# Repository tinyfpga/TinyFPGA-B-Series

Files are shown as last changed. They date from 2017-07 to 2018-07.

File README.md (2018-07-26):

[](https://travis-ci.org/tinyfpga/TinyFPGA-B-Series)

# TinyFPGA B2 Board
The TinyFPGA B2 board is a tiny FPGA board with a low cost per logic element and convenient USB bitstream programming capability.  It measures just 18mm x 36mm and is a perfect fit for breadboards.  

# TinyFPGA BX Repo has Moved
If you are looking for the TinyFPGA BX design files and examples, it is in a seperate repository: [TinyFPGA BX GitHub Repo](https://github.com/tinyfpga/TinyFPGA-BX).

## Features
The heart of the B-series boards is either a ICE40LP4K or ICE40LP8K FPGA from Lattice.  For full details on the ICE40 series of FPGAs you can read the [ICE40 Family Handbook](http://www.latticesemi.com/~/media/LatticeSemi/Documents/Handbooks/iCE40FamilyHandbook.pdf).

### FPGA Feature Summary
| | TinyFPGA B1 | TinyFPGA B2 |
|---|:---:|:---:|
| FPGA Chip |  ICE40LP4K  |  ICE40LP8K  |
| Logic Cells | 3,520 | 7,680 |
| Block RAM Bits | 80 KBit | 128 KBit  |
| Phase Lock Loops | 1 | 1 |
| User IO Pins | 23 | 23 |

### Common Features
+ Small form-factor that is breadboard friendly; plenty of space on either side for connecting jumpers or components.
+ Built-in USB interface for programming new FPGA bitstreams and user data to flash.
+ [4MBit of SPI Flash](http://datasheet.octopart.com/AT25SF041-SSHD-B-Adesto-Technologies-datasheet-62342976.pdf)
  + Bootloader bitstream takes up about 1MBit, user design bitstream will take another 1MBit, the rest is free to use for other purposes.
+ 3.3v and 1.2v Regulators
  + [3.3v LDO regulator](http://datasheet.octopart.com/MIC5504-3.3YM5-TR-Micrel-datasheet-61114938.pdf) can supply up to 300ma of current.  This leaves some headroom for user peripherals.
  + [1.2v LDO regulator](http://datasheet.octopart.com/MIC5365-1.2YC5-TR-Microchip-datasheet-8324343.pdf) can supply up to 150ma of current.  More headroom for user peripherals.
+ [Ultra Low-Power 16MHz MEMs Oscillator](http://www.mouser.com/ds/2/268/20005625A-1022977.pdf)
  + Consumes 1.3ma power when active.  
  + 50ppm stability

## Building your own TinyFPGA B1 or B2 Boards
It is possible to build the TinyFPGA B-Series boards by hand in a home lab.  However, it uses tiny 0402 surface mount capacitors and resistors and the ICE40 FPGAs used are in a 81 ball BGA package with 0.4mm pitch between the balls.  It is a challenging undertaking and will most likely result in some bad assembled boards along with the good.  I have used the following with success to hand assemble the prototype boards:
+ Parts for the TinyFPGA [B1](https://octopart.com/bom-tool/v110mo4B) or [B2](https://octopart.com/bom-tool/D9LH87Em)
+ [Lead-Free Solder Paste](https://www.amazon.com/gp/product/B00HKK6XHC)
+ [Stainless Steel Solder Paste Squeegee](http://dirtypcbs.com/store/details/14/solder-paste-squeegee)
+ [TinyFPGA B-Series Solder Paste Stencil](https://www.oshstencils.com)
  + You'll need to generate the gerber files and upload the solder paste layer.  You will want the stainless steel stencil, I do not believe the polymide will work with the fine pitch BGA package.
+ [TinyFPGA B-Series PCBs](https://oshpark.com/shared_projects/jGc1k4QL)
  + These boards require tighter tolerances than OSH Park advertises.  However, I have gotten lucky with some boards from OSH Park for this project and they have worked well.
+ [Precision Tweezers](https://www.amazon.com/Precision-Anti-static-Marrywindix-Electronics-Jewelry-making/dp/B00DVIEJ14) for placing parts on the board
+ Some sort of magnifying tool for placing parts ([magnifying glasses](https://www.amazon.com/dp/B01H8808H6), [magnifying lamp](https://www.amazon.com/Brightech-LightView-SuperBright-Magnifier-Adjustable/dp/B00UW2IRJ2), microscope)
+ [Reflow Oven](http://www.whizoo.com/)
  + I was using an electric griddle to reflow the A-series boards and it worked well enough.  However I didn't bother trying that with the micro BGA package on the B-series boards and I got a reflow oven kit.  This particular kit is excellent.
+ [Lattice FPGA Programmer](https://www.ebay.com/sch/i.html?_productid=533163279) or [Arduino board](https://www.arduino.cc/)
  + You will need this to load the bootloader onto the SPI Flash.  Once the bootloader is installed you can use the Python-based programmer application to program the board over USB.
  + Look in the [`programmer_arduino`](programmer_arduino) folder to load the bootloader onto the SPI Flash using an Arduino.

## Buy TinyFPGA B1 or B2 Boards
If you don't want to go through the hassle of ordering parts, tools, and supplies and assembling the boards yourself you can order professionally assembled and tested boards from [Tindie](https://www.tindie.com/stores/tinyfpga/) or the [TinyFPGA Store](http://store.tinyfpga.com).  These boards are not hobbyist-made, they are fabricated and assembled in a professional PCB fab that manufactures and assembles many other consumer, industrial and military electronics.  They go through an automated testing and programming process to ensure the board is healthy and ready to program over USB.

## Project Directory Structure
### board
This contains a [KiCad](http://kicad-pcb.org/) project with the schematic and layout of the B-series boards.  The board is designed with 4/4mil track size/spacing and 0.2mm hole size.  BOM lists for B1 and B2 boards are available here as well.

### bootloader
FPGA boards with USB bitstream programming capability typically use an expensive USB interface chip to provide this functionality.  The TinyFPGA B-series implement the USB bitstream programming capability within the FPGA itself.  This directory contains the verilog code that implements this bootloader.  The code is organized as an [iCEcube2](http://www.latticesemi.com/iCEcube2) project.  The bootloader itself works in the same way an Arduino bootloader works.  It is the first design to boot on the FPGA, if it is connected to a USB host it waits for a new bitstream to be programmed to the SPI flash, then reboots the FPGA to load the user design from flash.  If the board is not connected to a USB host or if there is no programmer application running on the host then the bootloader will quickly timeout and load the user design.  The bootloader does not consume any FPGA resources while the user design is loaded.

### programmer
The bootloader uses a simple protocol over a generic USB serial interface.  This directory contains a Python module for interfacing with the bootloader as well as a friendly Python GUI application for selecting and programming bitstreams.

### template
This is a template iCEcube2 project for developing your own designs to program onto the board.  It takes care of pin and clock constraints.  Just edit the TinyFPGA_B.v file to add your designs module(s).

## Project Log
For more information on the development and production of the B-Series please read and follow the [TinyFPGA B-Series Project Page](https://hackaday.io/project/26848-tinyfpga-b-series) at hackaday.io.

## License
The TinyFPGA B-Series project is an open source project licensed under GPLv3.  Please see the included LICENSE file for details.  If you do wish to distribute boards derived from this open source hardware project then you must also release the source files for the boards under GPLv3.  You are free to do this, but please improve upon the original design and provide a tangible benefit for users of the board.

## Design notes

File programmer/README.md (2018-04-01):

# Programmer

## Directory Structure

The programmer Python code is organized in a Python package.  The actual code for the programmer is located in the `tinyfpgab` directory in the `__init__.py` and `__main__.py` files.  The `setup.py` script is specific to the Python packaging system and should be be executed directly.  If you want to learn more about Python packaging take a look at the [Python packaging documentation](http://python-packaging.readthedocs.io/en/latest/minimal.html).  If you just want to run the programmer on the command-line, the best way is to install it using pip: `pip install tinyfpgab`.  The programmer script will then be added to your `PATH` variable as `tinyfpgab`.

## GUI

The GUI has been moved to the [TinyFPGA Programmer Application repo][gui-repo].
However, the `tinyfpgab` module can be used on its own with a command-line
interface:

[gui-repo]: https://github.com/tinyfpga/TinyFPGA-Programmer-Application

## CLI Installation

Install the commandline tool via Python's pip tool:
```
> pip install tinyfpgab
```

## CLI Usage
```
> tinyfpgab --help
usage: tinyfpgab [-h] [-l] [-p PROGRAM] [-b] [-c COM] [-d DEVICE] [-a ADDR]

optional arguments:
  -h, --help            show this help message and exit
  -l, --list            list connected and active TinyFPGA B-series boards
  -p PROGRAM, --program PROGRAM
                        program TinyFPGA board with the given bitstream
  -b, --boot            command the TinyFPGA B-series board to exit the
                        bootloader and load the user configuration
  -c COM, --com COM     serial port name
  -d DEVICE, --device DEVICE
                        device id (vendor:product); default is TinyFPGA-B
                        (1209:2100)
  -a ADDR, --addr ADDR  force the address to write the bitstream to
```

You can list valid ports with the `--list` option:

```
> tinyfpgab --list

    TinyFPGA B-series Programmer CLI
    --------------------------------
    Boards with active bootloaders:
        COM24

```

You can use the `--com` option to specify a specific port.  If you don't specify a port, it will use the first one in the list:

```
> tinyfpgab --program ..\icestorm_template\TinyFPGA_B.bin

    TinyFPGA B-series Programmer CLI
    --------------------------------
    Programming COM24 with ..\icestorm_template\TinyFPGA_B.bin
    Waking up SPI flash
    135100 bytes to program
    Erasing designated flash pages
    Writing bitstream
    Verifying bitstream
    Success!

```

## Testing

The tests can be run with [tox](https://tox.readthedocs.io/): just run the `tox` command.  If you don't have `tox` installed, read the tox documentation and install it first.

The code coverage will be generated as HTML pages in the `htmlcov` directory.

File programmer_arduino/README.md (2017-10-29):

# Programming with an Arduino

Programming the TinyFPGA using an Arduino (or compatible board) is useful in
the following cases:

 * You have overridden the TinyFPGA bootloader, so you cannot program the board
   any more and need a way to upload the bootloader again.

 * You have a project that needs a lot data to be stored in the Flash memory,
   and leaving the bootloader there takes too much place. In that case, simply
   upload your bitstream at the address `0` and you are free to use the
   remaining space.

## Hardware

:warning: **The TinyFPGA board is expecting 3.3V, but the Arduino board is
typically outputting 5V! We explain below how to go from 5V to 3.3V.**
:warning:

The following connections will be made:

| Arduino pin | TinyFPGA pin | Comment |
| :---: | :---: | :---: |
| 3.3V | 3.3V | |
| GND | G | |
| 10 | 17 | Through 5V-to-3.3V converter |
| 11 | 14 | Through 5V-to-3.3V converter |
| 12 | 15 | Through 5V-to-3.3V converter |
| 13 | 16 | Through 5V-to-3.3V converter |

To convert from 5V to 3.3V, a solution is to use a [voltage
divider](https://en.wikipedia.org/wiki/Voltage_divider) made of a few
resistors. By using `R1=470Ω` and `R2=1kΩ`, we should have an output close to
3.4V, which should be good:

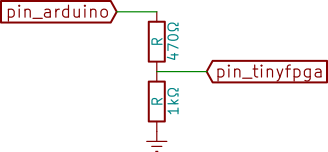
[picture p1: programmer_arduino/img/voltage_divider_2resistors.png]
Voltage divider with 2 resistors


If you don't have those specific resistor values, just take the same value
three times, the output should be close to 3.3V:

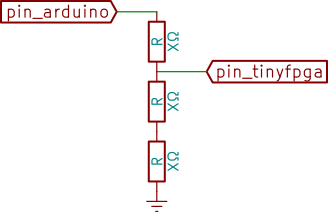
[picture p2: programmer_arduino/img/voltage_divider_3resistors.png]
Voltage divider with 3 resistors


The following shows all connections between the two boards:

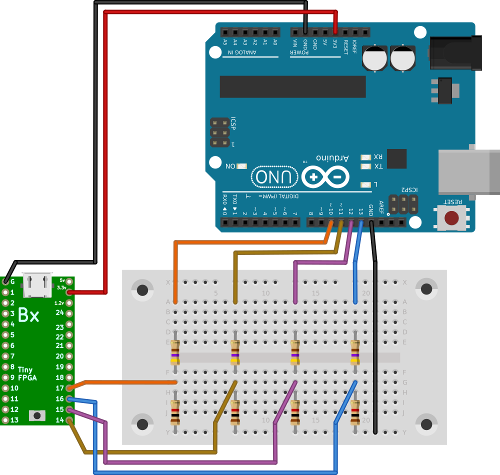
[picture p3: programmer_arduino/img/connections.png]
Overview


:warning: The TinyFPGA USB port should not be plugged at all at that point,
you can plug the Arduino board instead. :warning:

## Uploading the Arduino bootloader with PlatformIO

[PlatformIO](http://platformio.org/) is an open source ecosystem that make
using Arduino and other boards a breathe.

Once installed on your system, start by initialising the project from this
directory  (using the Arduino UNO board as an example):

    $ platformio init --board uno

Then, build the project and upload it to your Arduino:

    $ platformio run --target upload

That's all!

## Using the Arduino to program the TinyFPGA

We are going to use [the programmer CLI](../programmer).

First, find the vendor and product ID of your Arduino board. Doing so depends
on your operating system. For example on GNU/Linux:

    $ lsusb
    --<snip>--
    Bus 001 Device 002: ID 2341:0001 Arduino SA Uno (CDC ACM)
    --<snip>--

Now, use that vendor-product ID to program the Flash via the Arduino:

    $ ../programmer/tinyfpgab.py -d 2341:0001 -a 0 -p /snip/bootloader.bin

Notice the following in the command above:

 * The `-d` parameter specifies the device ID (vendor:product)
 * The `-a` parameter gives the address at which to program the bitstream: here
   we are writing at address 0, which is the correct address to put the
   TinyFPGA bootloader at.

Depending on the bitstream run by the FPGA, you may need to do the following:

 * Disconnect the Arduino from your computer, plug it back, and try again
 * Do the same, but this time press the reset button once before programming
 * Do the same, but this time hold the reset button before programming and
   *during the whole programming operation*: it is likely to last a minute or
   two, so be patient or use some non-metallic tool to hold the reset button
   down (a wooden clothes peg seems to do the job)

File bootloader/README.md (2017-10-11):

# USB Bootloader
The USB Bootloader implements a USB virtual serial port to SPI flash bridge.  From the host computer's perspective, it looks like a serial port.  This method was chosen because programming with serial ports is generally easier to understand than other USB-specific protocols.  Commands boot into the user configuration or access the SPI flash are all transfered over this interface.  

## Protocol
The protocol on top of the USB virtual serial port takes the form of requests and responses.  Only the host computer is able to initiate requests.  The bootloader on the FPGA can only respond to requests.

### Boot Command
```
Length: 1 byte

+=====================+
|    Request Data     |
+=====+========+======+
| Byte| Field  |Value |
+=====+========+======+
|  0  | Opcode | 0x00 |
+-----+--------+------+
```

The `Boot` command forces the TinyFPGA B-series board to exit the bootloader and configure the FPGA with the user design from SPI flash.  Once the user design is loaded onto the FPGA, the bootloader is no longer present and the user design has full control over the FPGA, including the USB interface.   

### Access SPI Command
```
Length: Variable

+================================+
|          Request Data          |
+=====+===================+======+
| Byte|       Field       | Value|
+=====+===================+======+
|  0  |       Opcode      | 0x01 |
+-----+-------------------+------+
|  1  |  Write Length Lo  | 0xWW |
+-----+-------------------+------+
|  2  |  Write Length Hi  | 0xWW |
+-----+-------------------+------+
|  3  |   Read Length Lo  | 0xRR |
+-----+-------------------+------+
|  4  |   Read Length Hi  | 0xRR |
+-----+-------------------+------+
|  5  | Write Data Byte 0 | 0xDD |
+-----+-------------------+------+
+-----+-------------------+------+
| n+5 | Write Data Byte n | 0xDD |
+-----+-------------------+------+

+================================+
|         Response Data          |
+=====+===================+======+
| Byte|       Field       | Value|
+=====+===================+======+
|  0  |  Read Data Byte 0 | 0xDD |
+-----+-------------------+------+
+-----+-------------------+------+
|  n  |  Read Data Byte n | 0xDD |
+-----+-------------------+------+
```

**NOTE: Even though the read and write fields are two bytes long, the current bootloader only supports read and write lengths of up to 16 bytes.  It will crash if larger lengths are used.**

The `Access SPI` command executes a transfer with the SPI flash.  SPI flash commands can have two phases:
1. Write phase.  Command opcode, address, and potentially data are shifted out the SPI master to the SPI flash.
2. Read phase.  Data is shifted from the SPI flash to the SPI master.

The `Write Length` and `Read Length` in the `Access SPI` command refer to these two phases.  In order to fully understand how to interact with the SPI flash you need to read the [datasheet for the SPI flash chip](http://datasheet.octopart.com/AT25SF041-SSHD-B-Adesto-Technologies-datasheet-62342976.pdf).  The datasheet contains a table that lists the commands the SPI flash chip supports.  

Here's a summary of the commands used to properly erase, program, and verify bitstreams on the SPI flash:

| Command | Opcode | Address Bytes | Dummy Bytes | Data Bytes | Datasheet Section |
|---|:---:|:---:|:---:|:---:|:---:|
| Resume | 0xAB | 0 | 0 | 0 | 11.4 |
| Read Man. and Dev. ID | 0x9F | 0 | 0 | 0 | 11.1 |
| Read Status Reg 1 | 0x05 | 0 | 0 | 1 | 10.1 |
| Block Erase 4 KBytes  | 0x20 | 3 | 0 | 0 | 7.2 |
| Block Erase 32 KBytes | 0x52 | 3 | 0 | 0 | 7.2 |
| Block Erase 64 KBytes | 0xD8 | 3 | 0 | 0 | 7.2 |
| Write Enable | 0x06 | 0 | 0 | 0 | 8.1 |
| Byte/Page Program | 0x02 | 3 | 0 | 1+ | 7.1 |
| Read Array | 0x0B | 3 | 1 | 1+ | 6.1 | 

## SPI Flash Programming Flow

The SPI flash needs to be accessed in a specific order to successfully program the bitstream.  The following pseudocode illustrates how the `tinyfpgab.py` programmer accesses the SPI flash:

```
// SPI flash will be in deep sleep, we need to wake it up
Issue Resume command     

// these two commands work around a bootloader bug
Read Status Register        
Read 16 bytes from addr 0  

// erase user flash area
For each 4k block from (0x30000) to (0x30000 + length(bitstream)):
    Issue Block Erase 4 KBytes at current block address
    Poll Read Status Reg 1 until bit 0 is cleared

// program new user bitstream into user flash area
For each 16 bytes from (0x30000) to (0x30000 + length(bitstream)):
    Issue write enable command
    Write 16 bytes of of the bitstream and increment write offset by 16 bytes
    
// verify bitstream data is correct
For each 16 bytes from (0x30000) to (0x30000 + length(bitstream)):
    Read 16 bytes of of the bitstream, compare to bitstream file, and increment read offset by 16 bytes

Issue Boot command to the bootloader
```

For exact details, see the [tinyfpgab.py](https://github.com/tinyfpga/TinyFPGA-B-Series/blob/master/programmer/tinyfpgab.py) programming script in this repo.

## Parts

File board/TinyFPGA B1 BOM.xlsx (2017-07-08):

Qty | Manufacturer | MPN | Schematic Reference | Description | Package | Polarity
1 | FCI | 10118192-0001LF | J3 | USB Micro Connector |  | pin locations only allow one correct orientation
1 | Microchip | MIC5365-1.2YC5-TR | U4 | 1.2v LDO |  | pin locations only allow one correct orientation
1 | Microchip | MIC5504-3.3YM5-TR | U2 | 3.3v LDO |  | pin locations only allow one correct orientation
4 | Murata | GRM155R61A105KE15D | C1, C2, C3, C4 | 1uF Ceramic Capacitor, 10V, X7R, 10% | 0402 | no polarity
1 | Lattice Semiconductor | ICE40LP4K-CM81 | U1 | FPGA | CM81 | circle on package at pin 1,
1 | Microchip | DSC6001CI2A-016.0000T or DSC6001CI2A-016.0000 | U3 | 16MHz Clock | CDFN3225-4LD-PL-1 | circle on package at pin 1
1 | Adesto Technologies | AT25SF041-SSHD-B | U5 | 4MBit SPI Flash | SOIC-8 3.9x4.9mm Pitch1.27mm | slight divot on package at pin 1
1 | C&K Components | PTS810 SJM 250 SMTR LFS | SW1 | Reset/Program Button |  | button is slightly wider in one dimension
3 | Vishay | CRCW040210K0FKED | R5, R6, R7 | 10k resistor, 1% tolerance, 1/16 watt | 0402 | no polarity
1 | KOA | RK73H1ETTP1000F | R4 | 100ohm resistor, 1% tolerance, 1/10 watt | 0402 | no polarity
2 | Panasonic | ERJ-2RKF68R0X | R2, R3 | 68ohm resistor, 1% tolerance, 1/10 watt | 0402 | no polarity
1 | Bourns | CR0402-FX-1501GLF | R1 | 1.5k resistor, 1% tolerance, 1/16 watt | 0402 | no polarity
4 | Wurth Electronics | 885012205050 | C12, C13, C14, C15 | 10nF Ceramic Capacitor, 25V, X7R, 10% | 0402 | no polarity
7 | Wurth Electronics | 885012105018 | C5, C7, C8, C9, C10, C11, C16 | 100nF Ceramic Capacitor, 25V, X5R, 10% | 0402 | no polarity
2 | TDK | C1608X5R0J106M080AB | C6, C17 | 10uF Ceramic Capacitor, 6.3V, X5R, 20% | 0603 | no polarity
1 | Murata | BLM18PG300SN1D | L1 | Ferrite Bead, 30ohm@100MHz impedance, 50mOhm DC resistance | 0603 | no polarity
 |  | Green items may be substituted with parts that have identical or better specifications
 |  | Red items may not be substituted with different part numbers

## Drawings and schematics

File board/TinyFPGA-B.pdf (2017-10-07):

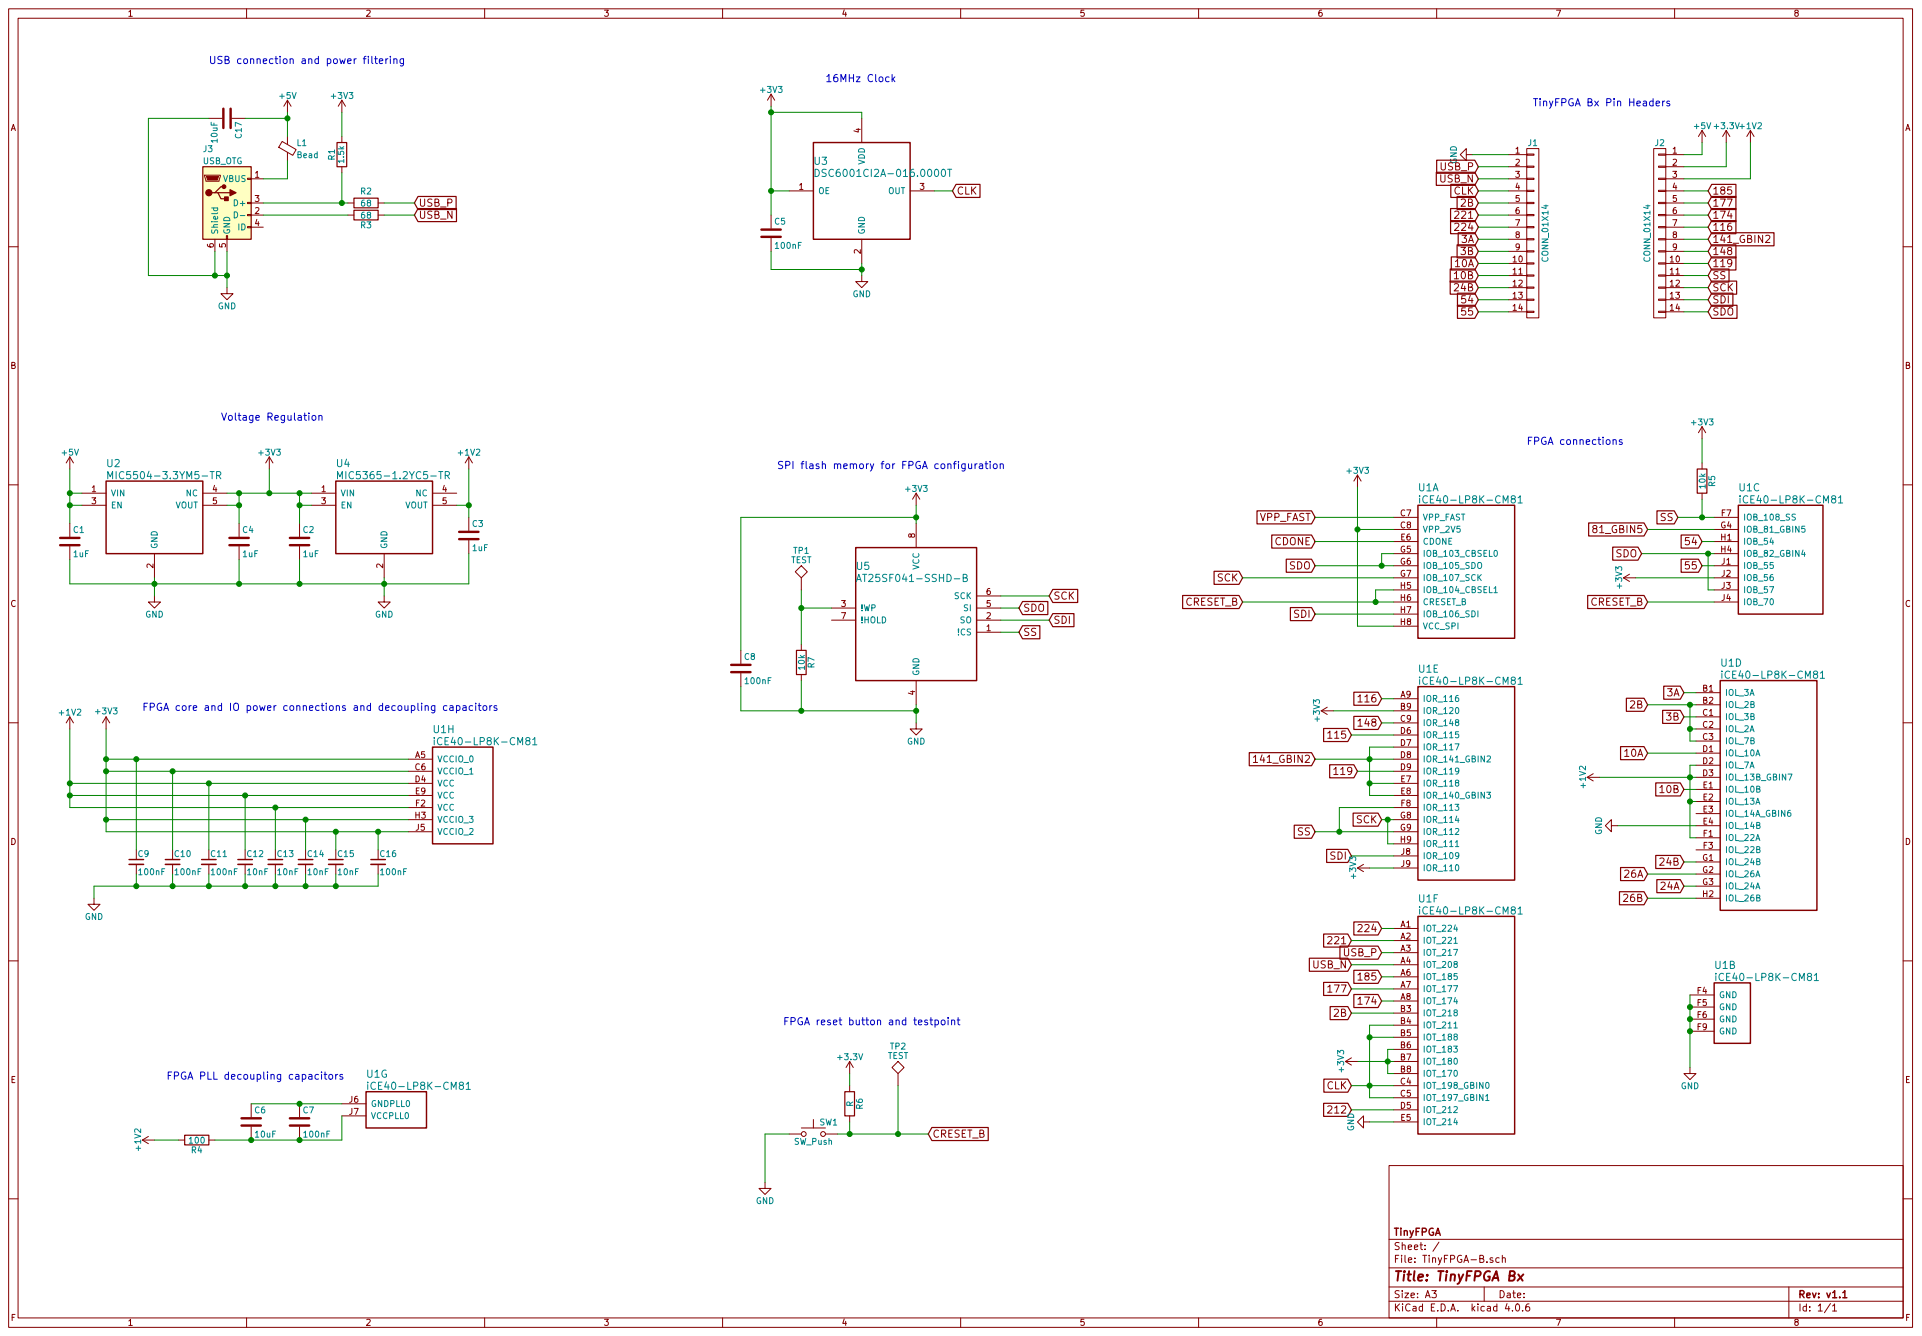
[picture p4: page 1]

USB connection and power filtering

TinyFPGA Bx Pin Headers

SPI flash memory for FPGA configuration

TP2 TEST FPGA core and IO power connections and decoupling capacitors

FPGA reset button and testpoint

FPGA PLL decoupling capacitors

File: TinyFPGA-B.sch Sheet: / TinyFPGA

Id: 1/1 Title: TinyFPGA Bx

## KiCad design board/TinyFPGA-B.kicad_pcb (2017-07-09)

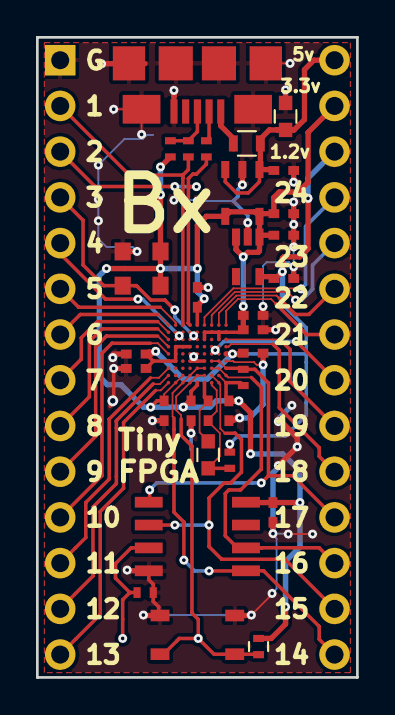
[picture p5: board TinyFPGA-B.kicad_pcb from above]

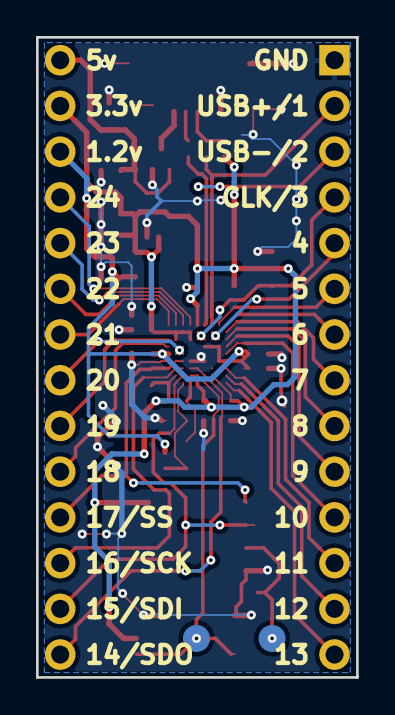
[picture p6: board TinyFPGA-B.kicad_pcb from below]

Board: 2 copper layers, 17.8 x 35.6 mm, 36 parts (2 on the bottom side), 35 nets.

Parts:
C1, C2, C3, C4: 1uF; C_0402_NoSilk
C5, C7, C8, C9, C10, C11, C16: 100nF; C_0402_NoSilk
C6, C17: 10uF; C_0603
C12, C13, C14, C15: 10nF; C_0402_NoSilk
J1, J2: CONN_01X14; Pin_Header_Straight_1x14_Pitch2.54mm
J3: USB_OTG; USB_Micro-B_Molex_47346-0001
L1: Bead; L_0603
R1: 1.5k; R_0402_NoSilk
R2, R3: 68; R_0402_NoSilk
R4: 100; R_0402_NoSilk
R5, R7: 10k; R_0402_NoSilk
R6: 100; R_0402
SW1: SW_Push; PTS_810_SMT_Switch
TP1, TP2: TEST; Measurement_Point_Round-SMD-Pad_Small
U1: iCE40-LP8K-CM81; CM81
U2: MIC5504-3.3YM5-TR; SC-70-C5
U3: DSC6001CI2A-016.0000T; CDFN3225-4LD-PL-1
U4: MIC5365-1.2YC5-TR; SC-70-C5
U5: AT25SF041-SSHD-B; SOIC-8_3.9x4.9mm_Pitch1.27mm

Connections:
2B: J1.5, U1.B2, U1.B3, U1.C2, U1.C3
3A: J1.8, U1.B1
3B: J1.9, U1.C1
10A: J1.10, U1.D1
10B: J1.11, U1.E1
24B: J1.12, U1.G1
54: J1.13, U1.H1
55: J1.14, U1.J1
116: J2.7, U1.A9
119: J2.10, U1.D9
141_GBIN2: J2.8, U1.D7, U1.D8, U1.E7, U1.E8
148: J2.9, U1.C9
174: J2.6, U1.A8
177: J2.5, U1.A7
185: J2.4, U1.A6
221: J1.6, U1.A2
224: J1.7, U1.A1
+1V2: C3.1, C11.1, C12.1, C13.1, J2.3, R4.2, U1.D2, U1.D3, U1.D4, U1.E2, U1.E9, U1.F1, U1.F2, U4.5
+3V3: C2.1, C4.1, C5.1, C8.1, C9.1, C10.1, C14.1, C15.1, C16.1, J2.2, R1.2, R5.1, R6.1, U1.A5, U1.B6, U1.B7, U1.B8, U1.B9, U1.C6, U1.C8, U1.H3, U1.H8, U1.J2, U1.J5, U1.J9, U2.4, U2.5, U3.1, U3.4, U4.1, U4.3, U5.8
+5V: C1.1, C17.1, J2.1, L1.1, U2.1, U2.3
CLK: J1.4, U1.B4, U1.B5, U1.C4, U1.C5, U3.3
CRESET_B: R6.2, SW1.2, TP2.1, U1.H5, U1.H6, U1.J4
GND: C1.2, C2.2, C3.2, C4.2, C5.2, C8.2, C9.2, C10.2, C11.2, C12.2, C13.2, C14.2, C15.2, C16.2, C17.2, J1.1, J3.5, J3.6, R7.2, SW1.1, U1.E4, U1.E5, U1.F4, U1.F5, U1.F6, U1.F9, U2.2, U3.2, U4.2, U5.4
unnamed: C6.1, C7.1, U1.J6
unnamed: C6.2, C7.2, R4.1, U1.J7
unnamed: J3.1, L1.2
unnamed: J3.2, R3.2
unnamed: J3.3, R1.1, R2.2
unnamed: R7.1, TP1.1, U5.3
SCK: J2.12, U1.G7, U1.G8, U1.H9, U5.6
SDI: J2.13, U1.H7, U1.J8, U5.2
SDO: J2.14, U1.G5, U1.G6, U1.H4, U1.J3, U5.5
SS: J2.11, R5.2, U1.F7, U1.F8, U1.G9, U5.1
USB_N: J1.3, R3.1, U1.A4
USB_P: J1.2, R2.1, U1.A3

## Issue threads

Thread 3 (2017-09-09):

Wrong VID:PID

donnie-j, 2017-09-09:
B2 boards which arrived this week have a different VID:PID than is expected by the programmer.  Here is a patch that allows the programmer to detect the board.

```diff --git a/programmer/tinyfpgab-programmer.py b/programmer/tinyfpgab-programmer.py
index 8b0d8ca..5b33579 100644
--- a/programmer/tinyfpgab-programmer.py
+++ b/programmer/tinyfpgab-programmer.py
@@ -78,7 +78,7 @@ def update_serial_port_list_task():
     global program_in_progress

     if not program_in_progress:
-        new_tinyfpga_ports = [i[0] for i in comports() if "1209:1200" in i[2]]
+        new_tinyfpga_ports = [i[0] for i in comports() if "1209:2100" in i[2]]

         if new_tinyfpga_ports != tinyfpga_ports:
             if com_port_sv.get() == "" and len(new_tinyfpga_ports) > 0:```

I still have a problem generating an Intel Hex file from the Yosys tools that the programmer will accept.  It's not clear to me if it's (say) a question of selecting the correct Intel Hex base address, or if the issue is communication with the board.

tinyfpga, 2017-09-09:
Hey @donnie-j, thanks for these issues and patches, I'll be reviewing and merging them shortly.

If you attach a hex file to a new issue and I'll try and reproduce the problem you are running into.

tinyfpga, 2017-09-09:
Another thing I remembered, the programmer application parses .hex files.  The .hex files are just a whitespace-seperated list of byte values starting at the least significant byte.  It does not currently support Intel hex files (with a .mcs extension).  I can add support for Intel hex this weekend.

donnie-j, 2017-09-09:
Thanks for this.

Actually I had figured out that .hex was not Intel hex.  If you are working on this, I think it is better (from a yosys point of view) to add a binary file reader.  I might post a patch if I get some time :)

tinyfpga, 2017-09-09:
Yeah, I really just want it to work without much fuss for anyone.  A [pull-request](https://help.github.com/articles/about-pull-requests/) for binary files would be awesome.  I'll be adding support for the [TinyFPGA Programmer](https://github.com/tinyfpga/TinyFPGA-A-Programmer) to the GUI this weekend so I'll be making some commits.

tinyfpga, 2017-09-09:
I moved the programmer GUI to the [TinyFPGA Programmer repo](https://github.com/tinyfpga/TinyFPGA-Programmer-Application) which has the correct PID and VID.

Closed 2017-09-09.

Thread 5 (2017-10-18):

bootloader testbench

tinyfpga, 2017-10-18:
The bootloader has no testbench.  There are bugs in the bootloader that are currently being worked around, but this makes it difficult to write programmer software for the board.  This enhancement is to create unit-level testbenches and test suites for the various bootloader verilog modules.

cocotb and Python will be used for the testbench and tests.

https://github.com/potentialventures/cocotb

tinyfpga, 2018-04-01:
A testbench is implemented in the new bootloader https://github.com/tinyfpga/TinyFPGA-Bootloader/

Closed 2018-04-01.

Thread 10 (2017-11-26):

Lost warmboot capabilities after recompiling bootloder

facchinm, 2017-11-26:
Hi Luke,
first of all, thank you!!! Your project is super cool.
I was studying the bootloader code to integrate some parts into another project;
after recompiling it with iCeCube 2017.01.27914 (on Linux) and flashing it at address 0x0 it looks like the "bootloader" feature (warmboot) disappeared. I can flash the bootloader over itself just fine, I can also flash an "application" at 0x30000 but it doesn't "boot" it.
Am I missing something obvious? Could you share the actual bitmap you are flashing in production so I can try it and report if it behaves differently?
Thanks a lot and keep on with your awesome project!

tinyfpga, 2017-11-26:
There is some special sauce that needs to go into the bitstream to enable warmboot.  It basically is like a header that tells the warmboot feature the addresses of the different configuration images.

I have posted the original firmware on the discourse: http://discourse.tinyfpga.com/t/programmer-for-b2-dodgy/86/28

I’ll try and write up instructions on how to enable the warmboot feature soon.  You have to use the Lattice deployment tool to process the bootloader bitstream and a dummy user bitstream.  It combines them both into one file along with the necessary vector information.

facchinm, 2017-11-26:
Sorry to bother you but I'm still unable to bring the bootloader back to life.
Renaming it to `hex` doesn't make `tinyfpgab` programmer happy (it expects a clean hex file, I believe).
Running `hex2bin` produces a suitable binary (the size is 331KB) but flashing it doesn't bring the ACM interface back. Am I (still) missing something :slightly_smiling_face: ?
Thanks again!

tinyfpga, 2017-11-26:
What hex2bin utility are you using?  Not sure it supports intel hex
correctly.  Give me some more info on the utility you are using and where
to find it.

On Sun, Nov 26, 2017 at 8:54 AM Martino Facchin <notifications@github.com>
wrote:

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

facchinm, 2017-11-26:
I'm using https://sourceforge.net/projects/hex2bin/?source=navbar with default parameters. The output looks sane; FYI, I'm following this procedure:
 ```
mv fw.mcs fw.hex
hex2bin fw.hex
tinyfpgab -p fw.bin -d 2341:8037 -a 0
```

facchinm, 2017-11-27:
I've been able to overcome the problem in this way:
* Pad some blank to the compiled booloader bitstream
```
dd if=/dev/zero of=blank.bin bs=1 count=90000
cat TinyFPGA_B_bitmap.bin blank.bin > TinyFPGA_B_bitmap2.bin
```
* Use `icemulti` to enable multiboot features
```
icemulti -c TinyFPGA_B_bitmap2.bin -a10000 -p0 example.bin -v -o /tmp/fw3.bin
tinyfpgab -p /tmp/fw3.bin -a0
```

This way it looks like it's working; I'm attaching the resulting bin if anyone is interested; I'll close the issue as soon as I make sure there is no side effect in this procedure.

[tinyfpga_bootloder.zip](https://github.com/tinyfpga/TinyFPGA-B-Series/files/1507548/tinyfpga_bootloder.zip)

tinyfpga, 2017-12-17:
Hey @facchinm, can you confirm your method is working with no side-effects?  If so, I can add this to the documentation.

facchinm, 2017-12-18:
It's working like a charm :smile: The only "problem" is that `icemulti` tool is much better at arranging the partitions at power of 2 boundaries, so `0x30000` doesn't play well with it. I finally decided to leave the default 0x20000 (since the bootloader fits in it) and get a bit more space in the flash. But to achieve it I had to modify the flasher so it's not really a neat workaround but I'm fine with it :wink:

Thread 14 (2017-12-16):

tinyfpgab --boot works only after the second execution

afiskon, 2017-12-16:
For some reason the first execution has no effect with B2 board.

cr1901, 2017-12-28:
I can confirm this on Windows 7 using libwdi's `usbser.sys` driver. Though I could've sworn in the past the `tinyfpgab -b` boot invocation worked the first time, neither my Nov 10 copy nor Nov 1st copy of the repo function correctly (i.e. they both require me to pass `--boot` twice).

In addition the device does not detach from the bus after the user bitstream is loaded.

tinyfpga, 2018-04-01:
This won't be fixed in this legacy version of the bootloader.  However it is fixed in https://github.com/tinyfpga/TinyFPGA-Bootloader/ and there will be an upgrade process at some point to upgrade the B2 boards from the legacy bootloader to the new one.

Closed 2018-04-01.

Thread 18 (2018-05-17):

Remove B1 board?

mithro, 2018-05-17:
The B1 board was going to have a B1 using the iCE40LP4K but it didn't make much sense pricewise?

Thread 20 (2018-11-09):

unable to program tinyFPGA BX under windows 10

simonbeaudoin0935, 2018-11-09:

RRob777, 2021-03-12:
Hello,

I have the same problem.
When I want to program my Tiny FPGA BX I get this error message: "Unable to communicate with TinyFPGA. Reconnect and reset TinyFPGA before programming.".

I am also using windows 10.
Does anyone have a solution?

simonbeaudoin0935, 2021-03-13:
No, never worked. I wanted to throw thia shit in the garbage, but ended up
writing my own programmer using an arduino (mega, but a uno would do).
Solder SPI pins to the tinyfpga flash pads. Anyway, it worked great this way

Compile que Qt application, and then flash this bitch

https://github.com/simonbeaudoin0935/TinyFPGA-Programmer

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

RRob777, 2021-03-13:
Hi.
I found the solution.
I use iCEcube2 (from Lattice) to design the VHDL code and to configure the pins used (order, layout, pull-up...). iCEcube2 then provides me a binary file (.bin).
I thought to use the TinyFPGA-Programmer software but there is a problem with it (as explained above).

--> 1. The solution to program the Tiny FPGA BX is to follow carefully the instructions of this site stopping at point 3 (before downloading Atom):

TinyFPGA BX User Guide : https://tinyfpga.com/bx/guide.html

*If you encounter problems during the installation of the modules (Apio, tinyprog...) do not hesitate to type your error message (which appeared on the Windows command prompt) on google. There are often forums that have solved problems.
**I have encountered this problem: No module named pyrsistent.
Write in the Windows command prompt (cmd): pip install "pyrsistent==0.15.7"

2. Then follow the instructions on this site from point 13 and stop after doing point 16:

https://www.centennialsoftwaresolutions.com/post/install-remove-tools-for-tinyfpga-bx-programming-and-program-the-board-on-windows-7-sp1

And there, if everything went well, you have programmed your Tiny FPGA BX.
This method allows you to program your Tiny FPGA BX with the Windows command prompt (from a binare file (.bin)).
For information, I am on Windows 10.

RRob777, 2021-03-13:
To reprogram your Tiny FPGA BX the next time, repeat step 2 after generating your binary file (.bin).

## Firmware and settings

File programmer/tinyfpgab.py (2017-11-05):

#!/usr/bin/env python2

import struct
import time


class TinyFPGAB(object):
    def __init__(self, ser, progress=None):
        self.ser = ser
        self.spinner = 0
        if progress is None:
            self.progress = lambda x: x
        else:
            self.progress = progress

    def is_bootloader_active(self):
        time.sleep(0.1)
        for i in range(6):
            self.wake()
            time.sleep(0.001)
            self.read(0, 16)
            time.sleep(0.001)
            self.wake()
            time.sleep(0.001)
            devid = self.read_id()
            expected_devid = '\x1f\x84\x01'
            if devid == expected_devid:
                return True
            time.sleep(0.05)
        return False

    def cmd(self, opcode, addr=None, data='', read_len=0):
        assert isinstance(data, str)
        cmd_read_len = read_len + 1 if read_len else 0
        addr = '' if addr is None else struct.pack('>I', addr)[1:]
        write_string = chr(opcode) + addr + data
        cmd_write_string = '\x01{}{}'.format(
            struct.pack('<HH', len(write_string), cmd_read_len),
            write_string,
        )
        self.ser.write(cmd_write_string)
        self.ser.flush()
        return self.ser.read(read_len)

    def sleep(self):
        self.cmd(0xb9)

    def wake(self):
        self.cmd(0xab)

    def read_id(self):
        return self.cmd(0x9f, read_len=3)

    def read_sts(self):
        return self.cmd(0x05, read_len=1)

    def read(self, addr, length):
        data = ''
        while length > 0:
            read_length = min(16, length)
            data += self.cmd(0x0b, addr, '\x00', read_len=read_length)
            self.progress(read_length)
            addr += read_length
            length -= read_length
        return data

    def write_enable(self):
        self.cmd(0x06)

    def write_disable(self):
        self.cmd(0x04)

    def wait_while_busy(self):
        # FIXME: this is a workaround for a bug in the bootloader verilog.  if
        #        the status register read comes too early, then it corrupts the
        #        SPI flash write in progress.  this busy loop waits long enough
        #        such that the write data has finished and data corruption is
        #        no longer possible.
        self._delay_micros(70)
        while ord(self.read_sts()) & 1:
            self._delay_micros(10)

    def _erase(self, addr, length):
        opcode = {
            4 * 1024: 0x20,
            32 * 1024: 0x52,
            64 * 1024: 0xd8,
        }[length]
        self.write_enable()
        self.cmd(opcode, addr)
        self.wait_while_busy()

    def erase(self, addr, length):
        possible_lengths = (1, 4 * 1024, 32 * 1024, 64 * 1024)

        while length > 0:
            erase_length = max(p for p in possible_lengths
                               if p <= length and addr % p == 0)

            if erase_length == 1:
                # there are no opcode to erase that much
                # either we want to erase up to multiple of 0x1000
                # or we want to erase up to length

                # start_addr                            end_addr
                # v                                     v
                # +------------------+------------------+----------------+
                # |       keep       |      erase       |      keep      |
                # +------------------+------------------+----------------+
                #  <- start_length -> <- erase_length -> <- end_length ->

                start_addr = addr & 0xfff000
                start_length = addr & 0xfff
                erase_length = min(0x1000 - start_length, length)
                end_addr = start_addr + start_length + erase_length
                end_length = start_addr + 0x1000 - end_addr

                # read data we need to restore later
                if start_length:
                    start_read_data = self.read(start_addr, start_length)
                if end_length:
                    end_read_data = self.read(end_addr, end_length)

                # erase the block
                self._erase(start_addr, 0x1000)

                # restore data
                if start_length:
                    self.write(start_addr, start_read_data)
                if end_length:
                    self.write(end_addr, end_read_data)

            else:
                # there is an opcode to erase that much data
                self.progress(erase_length)
                self._erase(addr, erase_length)

            # update
            length -= erase_length
            addr += erase_length

    def _delay_micros(self, micros):
        import timeit
        seconds = micros / 1000000.0
        t = timeit.default_timer()
        while timeit.default_timer() - t < seconds:
            self.spinner = (self.spinner + 1) & 0xff

    # don't use this directly, use the public "write" function instead
    def _write(self, addr, data):
        self.write_enable()
        self.cmd(0x02, addr, data)
        self.wait_while_busy()
        self.progress(len(data))

    def write(self, addr, data):
        while data:
            dist_to_256_byte_boundary = 256 - (addr & 0xff)
            write_length = min(16, len(data), dist_to_256_byte_boundary)
            self._write(addr, data[:write_length])
            data = data[write_length:]
            addr += write_length

    def program(self, addr, data):
        self.progress("Erasing designated flash pages")
        self.erase(addr, len(data))

        self.progress("Writing bitstream")
        self.write(addr, data)

        self.progress("Verifying bitstream")
        read_back = self.read(addr, len(data))

        if read_back == data:
            self.progress("Success!")
            return True
        else:
            self.progress("Need to rewrite some pages...")

            self.progress(
                "len: {:06x} {:06x}"
                .format(len(data), len(read_back)))

            mismatch_4k_pages = set()
            for i in range(min(len(data), len(read_back))):
                if read_back[i] != data[i]:
                    mismatch_4k_pages.add(i >> 12)

            for page in mismatch_4k_pages:
                page_offset = page << 12
                page_addr = addr + page_offset
                page_len = min(4 * 1024, len(data) - page_offset)
                page_data = data[page_offset:page_offset + page_len]
                self.progress("rewriting page {:06x}".format(page_addr))
                success = True
                for attempt in range(6):
                    self.erase(page_addr, page_len)
                    self.write(page_addr, page_data)
                    page_read_back_data = self.read(page_addr, page_len)

                    if len(page_read_back_data) != len(page_data):
                        success = False
                    else:
                        for i in range(page_len):
                            if page_read_back_data[i] != page_data[i]:
                                self.progress(
                                    "        diff {:06x}: {:02x} {:02x}"
                                    .format(
                                        i,
                                        ord(page_read_back_data[i]),
                                        ord(page_data[i])))
                                success = False

                    if success:
                        break
                    else:
                        time.sleep(0.1)

                if not success:
                    self.progress("Verification Failed!")
                    return False

            self.progress("Success!")
            return True

    def boot(self):
        self.ser.write("\x00")
        self.ser.flush()

    def slurp(self, filename):
        with open(filename, 'rb') as f:
            bitstream = f.read()
        if filename.endswith('.hex'):
            bitstream = ''.join(chr(int(i, 16)) for i in bitstream.split())
        elif not filename.endswith('.bin'):
            raise ValueError('Unknown bitstream extension')
        return (0x30000, bitstream)

    def program_bitstream(self, addr, bitstream):
        self.progress("Waking up SPI flash")
        self.progress(str(len(bitstream)) + " bytes to program")
        if self.program(addr, bitstream):
            self.boot()
            return True

        # FIXME: printing out this spinner ensures the busy loop in _write is
        #        not optimized away
        print "Your lucky number: " + str(self.spinner)

        return False


if __name__ == '__main__':
    import sys
    import argparse
    import serial
    from serial.tools.list_ports import comports

    parser = argparse.ArgumentParser()

    parser.add_argument("-l", "--list", action="store_true",
                        help="list connected and active TinyFPGA B-series "
                             "boards")
    parser.add_argument("-p", "--program", type=str,
                        help="program TinyFPGA board with the given bitstream")
    parser.add_argument("-b", "--boot", action="store_true",
                        help="command the TinyFPGA B-series board to exit the "
                             "bootloader and load the user configuration")
    parser.add_argument("-c", "--com", type=str, help="serial port name")
    parser.add_argument("-d", "--device", type=str, default="1209:2100",
                        help="device id (vendor:product); default is "
                             "TinyFPGA-B (1209:2100)")
    parser.add_argument("-a", "--addr", type=int,
                        help="force the address to write the bitstream to")

    args = parser.parse_args()

    print ""
    print "    TinyFPGA B-series Programmer CLI"
    print "    --------------------------------"

    device = args.device.lower().replace(':', '')
    if len(device) != 8 or not all(c in '0123456789abcdef' for c in device):
        print "    Invalid device id, use format vendor:product"
        sys.exit(1)
    device = '{}:{}'.format(device[:4], device[4:])
    print "    Using device id {}".format(device)
    active_boards = [p[0] for p in comports() if device in p[2]]

    # find port to use
    active_port = None
    if args.com is not None:
        active_port = args.com
    elif not active_boards:
        print "    No port was specified and no active bootloaders found."
        print "    Activate bootloader by pressing the reset button."
        sys.exit(1)
    elif len(active_boards) == 1:
        print "    Only one board with active bootloader, using it."
        active_port = active_boards[0]
    else:
        print "    Please choose a board with the -c option."

    # list boards
    if args.list or active_port is None:
        print "    Boards with active bootloaders:"
        for p in active_boards:
            print "        " + p
        if len(active_boards) == 0:
            print "        No active bootloaders found.  Check USB connections"
            print "        and press reset button to activate bootloader."

    # program the flash memory
    elif args.program is not None:
        print "    Programming " + active_port + " with " + args.program

        def progress(info):
            if isinstance(info, str):
                print "    " + info

        for attempt in range(3):
            with serial.Serial(active_port, 115200, timeout=0.2,
                               writeTimeout=0.2) as ser:
                fpga = TinyFPGAB(ser, progress)
                (addr, bitstream) = fpga.slurp(args.program)
                if args.addr is not None:
                    addr = args.addr
                if addr < 0:
                    print "    Negative write addr: {}".format(addr)
                    sys.exit(1)
                if addr + len(bitstream) >= 0x400000:
                    print "    Write addr over 4Mio: {}".format(addr)
                    sys.exit(1)
                if not fpga.is_bootloader_active():
                    print "    Bootloader not active"
                    continue
                print "    Programming at addr {:06x}".format(addr)
                if fpga.program_bitstream(addr, bitstream):
                    sys.exit(0)
                else:
                    continue

    # boot the FPGA
    if args.boot:
        print "    Booting " + active_port
        with serial.Serial(active_port, 115200, timeout=0.2,
                           writeTimeout=0.2) as ser:
            fpga = TinyFPGAB(ser)
            fpga.boot()

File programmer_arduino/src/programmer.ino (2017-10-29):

#include <SPI.h>

// SS:   pin 10
// MOSI: pin 11
// MISO: pin 12
// SCK:  pin 13


void setup(void) {
    SPI.begin();
    SPI.setDataMode(0);
    SPI.setBitOrder(MSBFIRST);

    Serial.begin(115200);
}


void serial_read(unsigned char * buf, int length) {
    while(!Serial.available()) {}
    Serial.readBytes(buf, length);
}


void loop(void) {
    unsigned char opcode, write_lo, write_hi, read_lo, read_hi;
    unsigned char write_buf[130], read_buf[130];

    serial_read(&opcode, 1);
    if(opcode == 0x01) {  // access SIP command

        // read parameters from serial
        serial_read(&write_lo, 1);
        serial_read(&write_hi, 1);
        serial_read(&read_lo, 1);
        serial_read(&read_hi, 1);
        if(write_lo > 128 || write_hi != 0 || read_lo > 128 || read_hi != 0) {
            return;  // abort
        }
        serial_read(write_buf, write_lo);

        // SPI communication
        digitalWrite(SS, HIGH);
        digitalWrite(SS, LOW);
        for(unsigned char i = 0; i < write_lo; i++) {
            SPI.transfer(write_buf[i]);
        }
        for(unsigned char i = 0; read_lo && i < read_lo - 1; i++) {
            read_buf[i] = SPI.transfer(0);
        }
        digitalWrite(SS, HIGH);

        // send reply to serial
        if(read_lo) {
            Serial.write(read_buf, read_lo - 1);
        }
    } else {
        // ignore other opcodes (e.g. boot)
    }
}

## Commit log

2017-07-08 first commit of the schematic, pcb layout, and BOM files
    [TinyFPGA B1 BOM.xlsx, TinyFPGA B2 BOM.xlsx, TinyFPGA-B.kicad_pcb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]
2017-07-08 adding TinyFPGA B-Series programmer source code
    [installer.cfg]
2017-07-09 Update README.md
    added extra information about the board itself as well as high level parts, tools, and supplies necessary to build your own.
2017-07-09 ignore KiCad backup files and gerbers
2017-07-09 added template iCEcube2 project to use as starting point for user designs
    [TinyFPGA-B.kicad_pcb]
2017-08-05 updated USB VID:PID to 1209:2100
2017-08-28 testing updates, new PID for programmer, NAK fix
2017-10-07 updates for manufacturing, schematic pdf
    [TinyFPGA-B.sch]
2017-10-17 workaround bug in bootloader that macos was hitting almost all the time
    [tinyfpgab.py]
2017-10-18 more stability fixes for MacOS
    [tinyfpgab.py]
2017-10-28 programmer: better output on program verify error
    [tinyfpgab.py]
2017-10-28 programmer: fix computation issue in erase
    This was occurring when the area to erase was less than 4096 bytes, did not
    start on a 4096 byte block, but did end on a 4096 block. In that case, the 4096
    block just after was read and re-written for nothing (it was not even erased!)
    [tinyfpgab.py]
2017-10-29 Add Arduino programmer
2017-11-04 untested fix for linux stability issues
    [tinyfpgab.py]
2017-11-05 fixed broken tests and bug found by unit test
    [test.py, tinyfpgab.py]
2017-11-26 Fix VID/PID containing letters not being matched
    On Linux, comports() returns an all uppercase result, so any programmer
    which vid/pid contains letters is no going to match
    [__main__.py]
